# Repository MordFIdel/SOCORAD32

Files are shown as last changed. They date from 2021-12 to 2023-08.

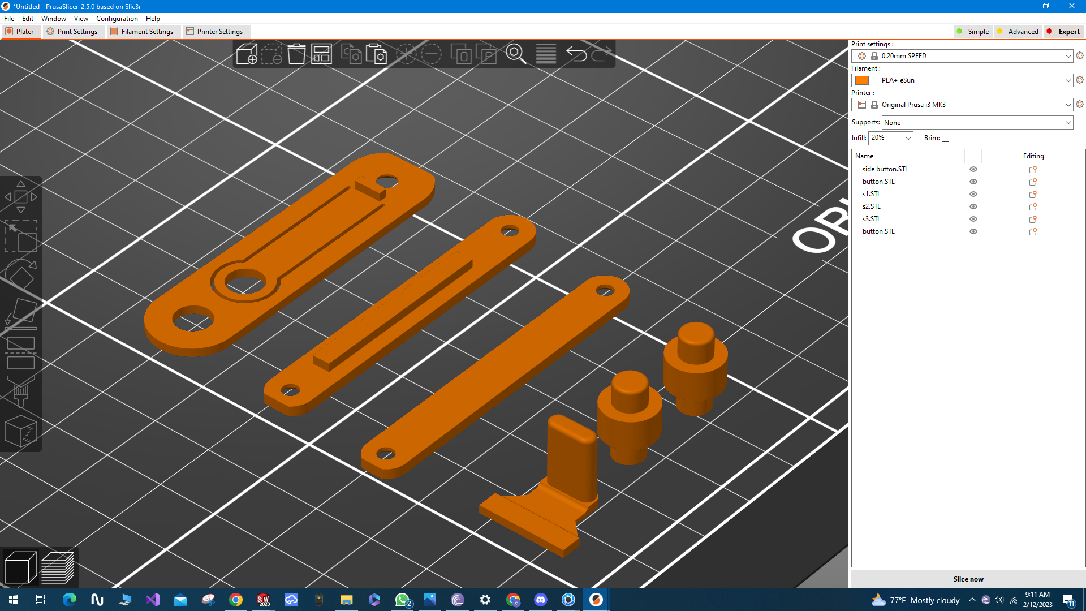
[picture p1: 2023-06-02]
3D_Files/Inner arrangement components.png

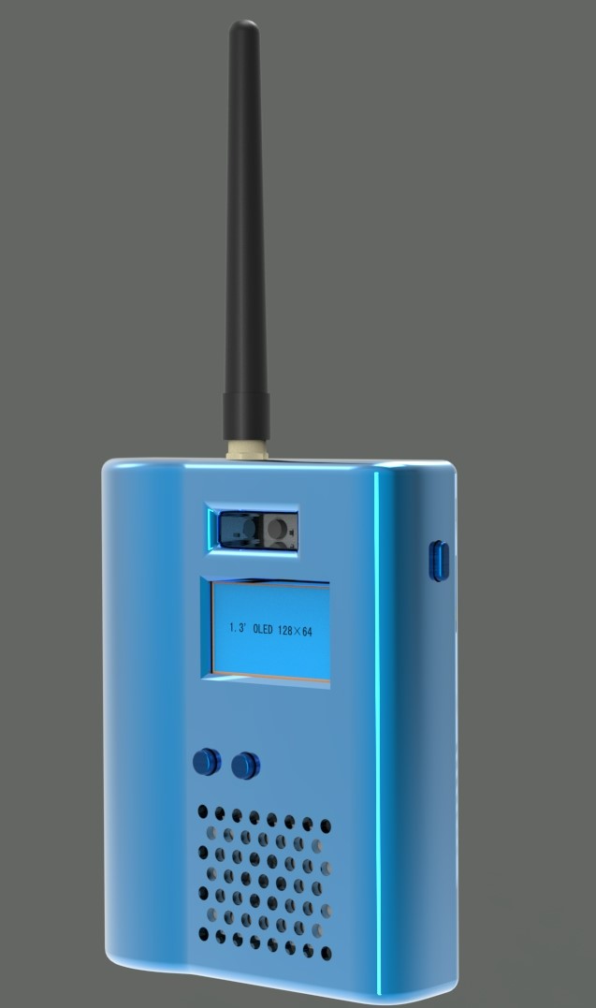
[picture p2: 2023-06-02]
3D_Files/3D.jpg

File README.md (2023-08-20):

# SOCORAD32 - ESP32 SOftware COntrolled RADio

<br/> (3D enclosure design already released)
<br/>
<br />Add a speaker and a battery, then you'll have a fully functional walkie talkie Radio. It shares the same properties as the commercial one. Can be used both for voice and data communication. Because it can communicate data, we can explore the amateur radio frequency for IoT.
<br/>Beyond communication, it is fully open source and hackable!
<br />The central module contains the special purpose RDA1846 IC. This same IC is used in commercial walkie talkies such as in Baofeng and Hytera. <br/>

<br/>Other of its peripherals is an onboard ESP32 for parameter settings (via Bluetooth or WiFi), control and storage. 
<br/>The ESP32 talks to the central module using simple AT commands. The specifications are listed below.

# Specifications
Frequency Range: 400-470mhz covers most countries allocated walkie talkie frequencies, especially the license free ones.
<br/> Frequency Step: 5K/6.25K/12.5K/25K
<br/> RF Output Power: 2W/1W/0.5W
<br/> Voice features, Tone Squelches, SMS cabapility:
<br/> Voice encryption (scrambling): 8 types
<br/> SMS Receive/Transformer, baudrate: 1200
<br/> CTCSS (38 groups) + CDCSS (83 groups)
<br/> Automatic elimination tail
<br/> Volume adjustable (1-8)
<br/> Squelch level adjustable (0-9)
<br/> MIC sensitivity level adjustable (1-8)
<br/> Sleep Mode (0.1μA)
<br/><br/>To talk to the module, a generic Bluetooth serial communication APP is used on the phone to connect to the ESP32 module which in turn communicates with the RF module via UART. Due to the SOCORAD32 rich features, it can be used for the following applications.

# Applications
Walkie Talkie
<br/>Intercom
<br/>Pager
<br/>IoT (data transmission module)
<br/><br/>The AT commands are in the repository. It includes commands for volume control, power output, RX/TX frequencies, voice activated exhange, squelching, etc.
<br/>The device contains a dedicated PTT button and extra buttons for user configurations.

<br/>SOCORAD32 high rez

## First run / Flashing
See [Final Firmware](Final_Firmware.md) for instructions

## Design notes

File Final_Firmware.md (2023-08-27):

Remember the changes we promised. It's here. The old software has too much bugs and so we decided to make this new one, using Bluetooth Low Energy. once you receive your unit. Just follow the simple steps below.

## ESP-IDF

This software is written in vs code using the [v4.4.4 ESP-IDF](https://github.com/espressif/idf-installer/releases/download/offline-4.4.4/esp-idf-tools-setup-offline-4.4.4.exe)

## Channels

Once you load this software, you can change the channel and volume with the provided buttons on the PCB. 
The channels are what is stored in the code. You are free to change the channel anyway you want, 
just edit the channel storage section in the code. Up to 50 channels or more can be edited to your
preference. 
To change the channel, Press and hold the button. To change volume, press once to change volume.
Connecting to your bluetooth phone, you can use the bluetooth serial software to also change channel by sendng AT+DMOCHN=8 (for channel 8)
AT+DMOCHN=10 (for channel 10).

### Edit Default Channels

To edit channel list, in the zip file, navigate to main, then ui.c You'll find this section at the top part of the code. 
This is same  for editing the ctcss. See screenshots below.

Channel list

ctcss list

## Bluetooth connection

This software allows simple and less complex use of the SOCORAD32 directly without bluetooth connection. 
Other functions provided by the walkie talkie module are accessible via bluetooth connections to a mobile device.
The connection process is simple. Using the 'Serial Bluetooth Terminal' android app as example (get from PlayStore), 

1. Firstly, connect the SCRD32 to your phone following your phone standard connection process. Passkey is 123456
2. Press the Menu button
3. Select Devices
4. Select Bluetooth LE
5. Press and hold the listed BLE device and choose edit.
6. Choose custom and enter the details as shown in the image below.

BLE connect process

7. Save the settings and voila!, your SOCORAD32 is connected. You can now use the AT commands directly. Input your commands through the app and view response from the SOCORAD32.

## Firmware

Link to FIrmware https://github.com/MordFIdel/SOCORAD32/blob/main/SCRD32%20firmware%20official.zip

## Beginners Guide For Windows

You have to load the firmware to the radio when you get it.
- Download the [ESP-IDF](#ESP-IDF) linked and install it.
- Download the [firmware zip](#firmware), "SCRD32 firmware official.zip", and - Extract the files to a folder with no spaces in name. For example you might extract it to "C:/SCRD32"
- Open the ESP-IDF powershell program
- Navigate to the folder you saved the firmware in, and type ```idf.py build``` This will build the firmware.
- Once the build is complete connect the radio and type ```idf.py -p [Port] flash```

- Change [Port] to the COM port of the socorad I. E. ```idf.py -p COM3 flash``` 

The firmware should now be loaded on the radio.

## Linux / Mac

Useful but optionnal dependency to speedup building: ccache

### Install esp-idf
```
mkdir -p ~/esp
cd ~/esp
git clone --recursive --branch v4.4.4 https://github.com/espressif/esp-idf.git
cd ~/esp/esp-idf
./install.sh esp32
```

### Clone repo
```
cd ~/
git clone https://github.com/MordFIdel/SOCORAD32.git
```
### Build & Flash
```
cd ~/SOCORAD32/SCRD32_firmware_official/
. $HOME/esp/esp-idf/export.sh (Run it everytime before you want to use esp-idf)
idf.py build
idf.py flash
```

You can directly use the esp-idf extension in Visual Code. Take care to utilize the correct version of ESP-IDF.

Or you could follow the [guide for installing the tool directly on Linux / Mac](https://docs.espressif.com/projects/esp-idf/en/latest/esp32/get-started/linux-macos-setup.html#)

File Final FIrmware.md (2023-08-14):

Remember the changes we promised. It's here. The old software has too much bugs and so we decided to make this new one, using Bluetooth Low Energy. once you receive your unit. Just follow the simple steps below.

This software is written in vs code using the [v4.4.4 ESP-IDF](https://github.com/espressif/idf-installer/releases/download/offline-4.4.4/esp-idf-tools-setup-offline-4.4.4.exe)

Once you load this software, you can change the channel and volume with the provided buttons on the PCB. 
The channels are what is stored in the code. You are free to change the channel anyway you want, 
just edit the channel storage section in the code. Up to 50 channels or more can be edited to your
preference. 
To change the channel, Press and hold the button. To change volume, press once to change volume.
Connecting to your bluetooth phone, you can use the bluetooth serial software to also change channel by sendng AT+DMOCHN=8 (for channel 8)
AT+DMOCHN=10 (for channel 10).

To edit channel list, in the zip file, navigate to main, then ui.c You'll find this section at the top part of the code. 
This is same  for editing the ctcss. See screenshots below.

Channel list

ctcss list

This software allows simple and less complex use of the SOCORAD32 directly without bluetooth connetion. 
Other functions provided by the walkie talkie module are accesssible via bluetooth connections to a mobile device.
The connection process is simple. Using the 'Serial Bluetooth Terminal' android app as example (get from PlayStore), 

1. Firstly, connect the SCRD32 to your phone following your phone standard connection process. Passkey is 123456
2. Press the Menu button
3. Select Devices
4. Select Bluetooth LE
5. Press and hold the listed BLE device and choose edit.
6. Choose custom and enter the details as shown in the image below.

BLE connect process

7. Save the settings and voila!, your SOCORAD32 is connected. You can now use the AT commands directly. Input your commands through the app and view response from the SOCORAD32.

Link to FIrmware https://github.com/MordFIdel/SOCORAD32/blob/main/SCRD32%20firmware%20official.zip

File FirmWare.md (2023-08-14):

[Firmware and guideline.zip](https://github.com/MordFIdel/SOCORAD32/files/10908223/Firmware.and.guideline.zip)

Here is a sample FW. Please note, the firmware is not developed by us, this is the work of the creator, DragonTV. KM6WZM
Please find him at https://www.instructables.com/member/dragonbtv/
The FirmWare is discussed at https://www.instructables.com/Arduino-Walkie-Talkie/

Thanks!

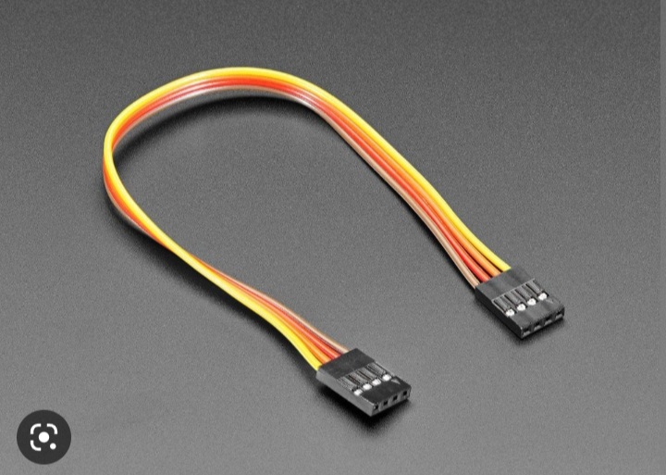
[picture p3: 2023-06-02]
3D_Files/display connector.jpg

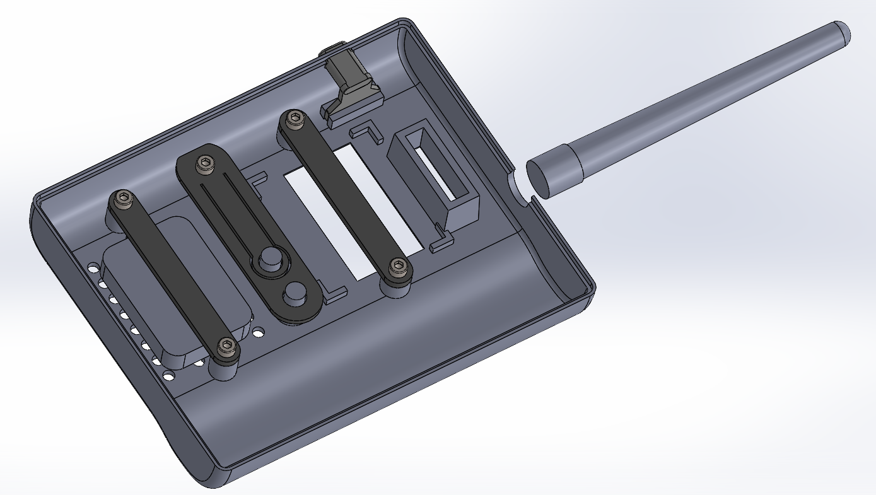
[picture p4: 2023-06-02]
3D_Files/Inner arrangement.png

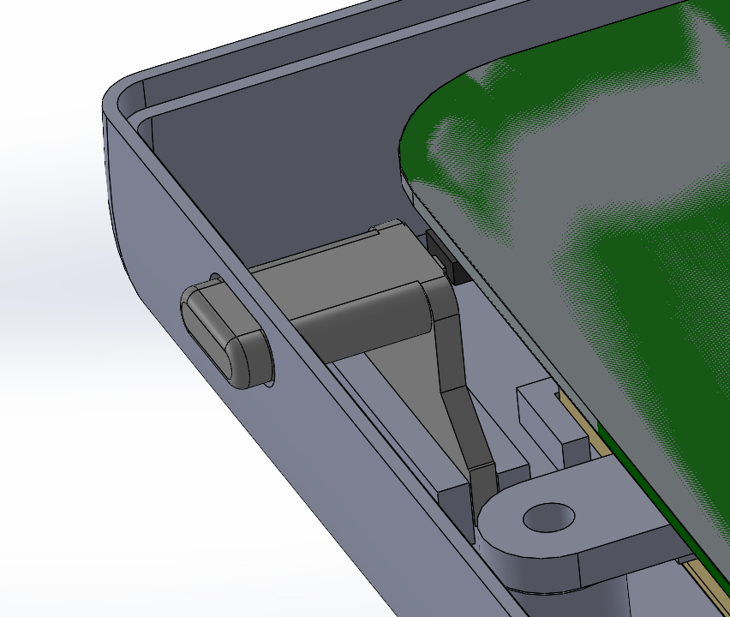
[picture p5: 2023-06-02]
3D_Files/button arrangement.png

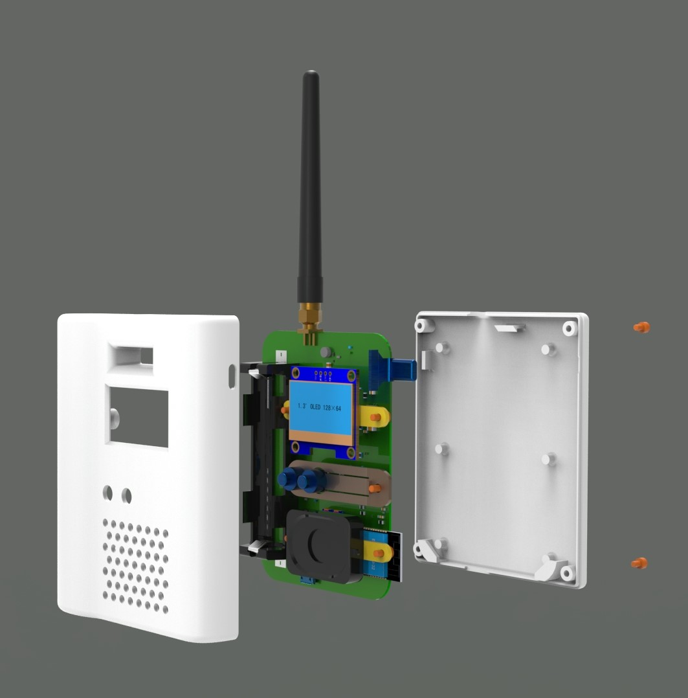
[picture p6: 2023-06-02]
3D_Files/exploded view original.jpg

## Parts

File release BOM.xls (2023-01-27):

Item # | *Designator | *Qty | *Mfg Part # | Description / Value | *Package/Footprint | Your Instructions / Notes | *Actual Purchase Mfg Part #
1 | C1, C9, C18, C21, C25, C32 | 6 | 10uf | 10µF ±10% 10V Ceramic Capacitor X5R 0603 _1608 Metric_ | 0603 |  | CC0603KRX5R6BB106
2 | C2, C10, C23 | 3 | GRM21BR71A225KA01L | SMT 0805 ceramic cap X7R 10V 2.2uF | 0805
3 | C3, C5, C6, C8, C11, C15, C17, C20, C24, C26, C28, C30, C35 | 13 | 100nf | 0.1ÂµF Â±10% 16V Ceramic Capacitor X7R 0402 _1005 Metric_ | 0402 |  | CC0402KRX7R7BB104
4 | C4, C14 | 2 | 220uf_6v3 | GRM31CR60J227ME11L | 1206 |  | GRM31CR60J227ME11L
5 | C7, C13, C16, C22, C27, C36 | 6 | CL05B104K05NNNC | Multilayer Ceramic Capacitors MLCC - SMD/SMT 100nF+/-10% 16V X7R 0402 | 0402
6 | C19 | 1 | GCM1885C2A2R0BA16D | SMD Capacitor C0G(EIA) with Capacitance: 2.0pF Tol. 0.1pF. Rated Voltage: 100Vdc | 0603
7 | C29 | 1 | GCM1885C2A6R0BA16D | SMD Capacitor C0G(EIA) with Capacitance: 6.0pF Tol. 0.1pF. Rated Voltage: 100Vdc | 0603
8 | C31 | 1 | GCM1885C2A2R5BA16D | SMD Capacitor C0G(EIA) with Capacitance: 2.5pF Tol. 0.1pF. Rated Voltage: 100Vdc | 0603
9 | C33 | 1 | GCM1885C2A4R0BA16D | SMD Capacitor C0G(EIA) with Capacitance: 4.0pF Tol. 0.1pF. Rated Voltage: 100Vdc | 0603
10 | C34 | 1 | CL10A105KP8NNNC | 1µF ±10% 10V Ceramic Capacitor X5R 0603 _1608 Metric_ | 0603
11 | D1 | 1 | SP0503BAHTG | 8.5V Clamp Ipp Tvs Diode Surface Mount SOT-143-4 | SOT-143-4
12 | D3, D5 | 2 | LTST-C191KRKT | Red 631nm LED Indication - Discrete 2V 0603 _1608 Metric_ | 603
13 | D4, D6 | 2 | 19217BHCZL1M2RY3T | blue 0603 Light Emitting Diodes (LED) ROHS | 0603
14 | IC1 | 1 | LM4871 | Audio Amplifiers 3-W, mono, analog input Class-AB audio amplifier 8-SOIC -40 to 85 | 8-SOIC |  | LM4871M/NOPB
15 | J1 | 1 | ZX62-B-5PA(33) | USB - micro B USB 2.0 Receptacle Connector 5 Position Surface Mount, Right Angle
16 | J2 | 1 | CONSMA013.062-G | SMA MALE EDGE MOUNT FOR 0.031 THICK BOARD
17 | L3 | 1 | LQP03TN2N0C02D | FIXED IND 2NH 600MA 150 MOHM SMD | 0603
18 | MIC1 | 1 | GMI4015P-2C-42DB | Through Hole,P=1.4mm Electret Condenser Microphone Source: Datasheet | GMI4015P2C42db
19 | Q3, Q4, Q5, Q6 | 4 | SS8050-G | Bipolar Transistors - BJT NPN TRANSISTOR 1.5A 40V | SOT-23-3 |  | MMBT2222LT1G
20 | R1, R4, R8, R25, R26, R27, R31, R32 | 8 | CRGCQ0805F47K | Fixed Resistor CRGCQ 0805 47K 1% | 0805
21 | R2 | 1 | CRGCQ0805F3K3 | Fixed Resistor CRGCQ 0805 3K3 1% | 0805
22 | R3, R10, R14, R23, R24 | 5 | RC0805FR-0710KL | RES SMD 10K OHM 1% 1/8W 0805 | 0805
23 | R5 | 1 | 1210W2F330LT5E | Thick Film Resistors - SMD 1210 1/2W 1% 0.33R T/R-5000 | 1210
24 | R6, R9, R11, R15, R18, R20, R21, R22, R28, R34 | 10 | 0603WAF1201T5E | Thick Film Resistors - SMD 0603 1/10W 1% 1.2K T/R-5000 | 0603
25 | R7, R12, R13, R17, R19 | 5 | 0402WGF4700TCE | Thick Film Resistors - SMD 0402 1/16W 1% 470R T/R-10000 | 0402
26 | R16, R29, R30, R33 | 4 | AC0402FR-072KL | AC Series 0402 0.063 W 2 kOhm ±1% ±100 ppm/°C SMT Thick Film Chip Resistor | 0402
27 | S1 | 1 | SKSCLAE010 | Black Button Tactile Switch, SPST-NO 50 mA 0.65mm Surface Mount Source: Datasheet
28 | SW1, SW3 | 2 | SKRPABE010 | Switch Tactile N.O. SPST Button J-Bend 0.05A 16VDC 1.57N SMD Automotive T/R
29 | SW4, SW5 | 2 | PTS645SM43SMTR92LFS | C & K COMPONENTS - PTS645SM43SMTR92LFS - SWITCH, SPST, 0.05A, 12VDC, SMD, 4.3MM Source: Datasheet
30 | U1 | 1 | NCP167BMX330TBG | Linear Voltage Regulator IC 1 Output 700mA 4-XDFN _1x1_ | 4-XDFN
31 | U3 | 1 | SR_FRS_2WUS | walkie talkie module
32 | U4 | 1 | TP4056 | Complete single cell Li-Ion battery with a constant current / constant voltage linear charger | SOP-8
33 | U5 | 1 | ESP32-WROOM-32 | SMD MODULE, ESP32-WROOM-32, ESP32-D0WDQ6 |  |  | ESP32-WROOM-32E-N4
34 | U6 | 1 | CH340C | USB to serial chip CH340 | SO-016

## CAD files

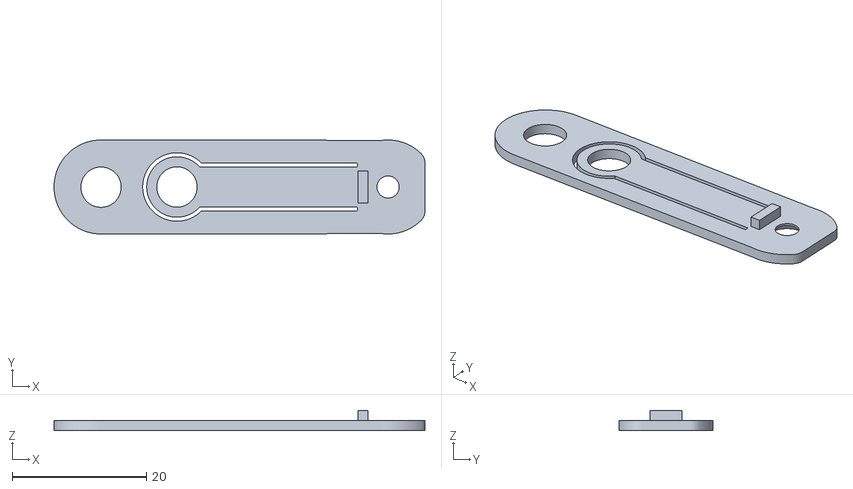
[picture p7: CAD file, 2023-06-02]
3D_Files/s1.STL
55.2 x 14.0 x 3.00

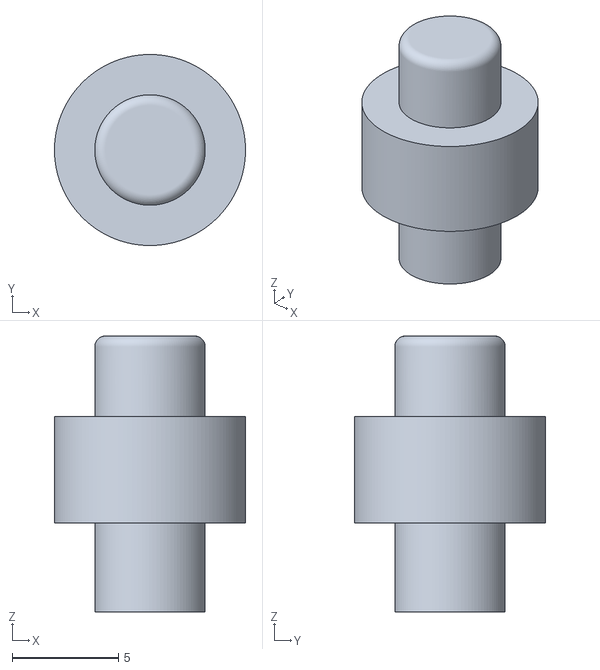
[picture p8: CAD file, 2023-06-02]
3D_Files/button.STL
9.00 x 9.00 x 13.0

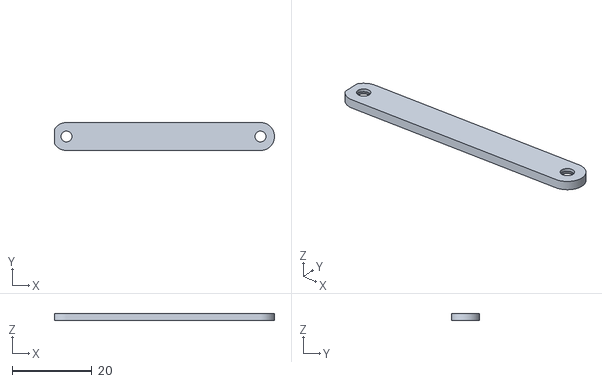
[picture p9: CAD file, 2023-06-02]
3D_Files/s3.STL
55.0 x 7.00 x 1.80

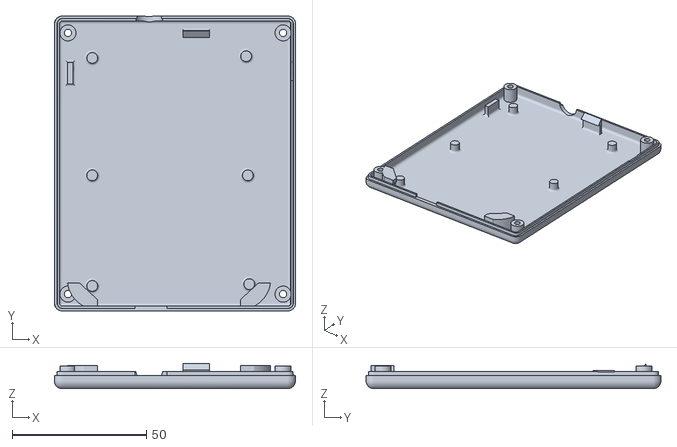
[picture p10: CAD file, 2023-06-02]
3D_Files/V01 - base-1.STL
90.0 x 110.0 x 9.50

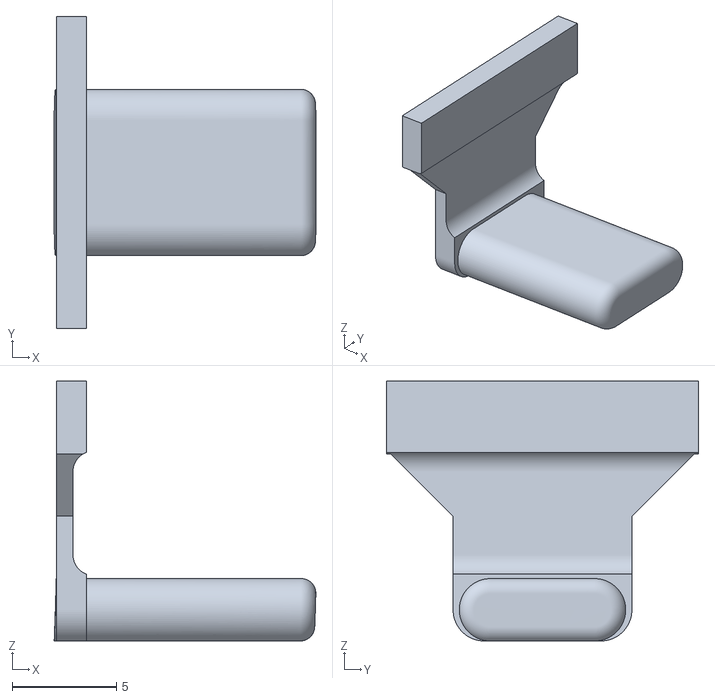
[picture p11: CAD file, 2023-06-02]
3D_Files/side button.STL
12.6 x 15.0 x 12.5

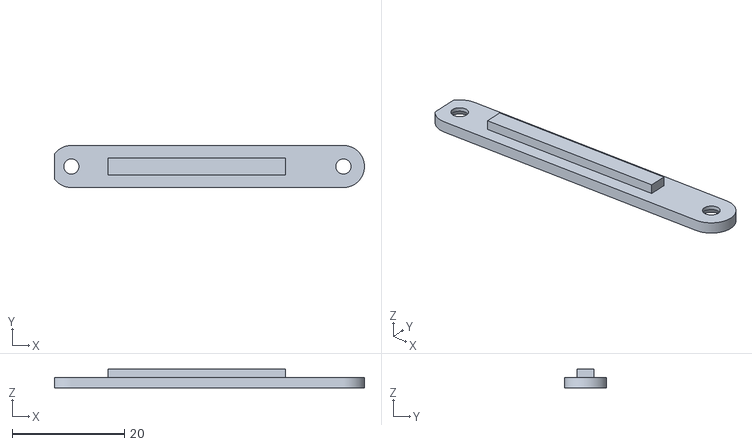
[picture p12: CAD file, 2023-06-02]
3D_Files/s2.STL
55.3 x 7.50 x 3.32

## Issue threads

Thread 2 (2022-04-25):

Can it transmit data from the ESP32?

DurandA, 2022-04-25:
Can the SOCORAD32 transmit data from the ESP32 or is the ESP32 only for the control of the transmission? Can the ESP32 be used to generate DTMF tones?

MordFIdel, 2022-04-26:
Yes it can transmit data from the ESP32. About DTMF, we've are yet to try DTMF, we are not sure.

DurandA, 2022-04-26:
I think from the pictures you are using a SA818 module which doesn't have any digital audio input. Do you feed the MIC input from the ESP DAC? Do you use a discrete chip like I2S->analog?

Also, when do you plan to start the Crowd Supply campaign? Your product sounds awesome.

MordFIdel, 2022-04-27:
I know SA818. The module I am using is slightly different. It houses it's own audio subsystem. The audio is not processed via ESP32. Although it is also a great idea to do that via DAC. The ESP32 only for controls and data transmission.

joyel24, 2023-01-20:
In my opinion, DAC from esp32 to the rf module is a feature that it must include.
It can be very useful to implement new data transmission protocols.
ADC would also be nice as it becomes possible to decode things directly from the ESP32.
A relatively simple circuit implementation but with a huge possible benefits in the end !

MordFIdel, 2023-01-20:
Yes, these are good ideas. For example, the DAC will enable direct audio transmission from a mobile phone for example. Mobile phone audio→Bluetooth→ESP32→DAC→RF module

I will look into this.

MordFIdel, 2023-01-20:
Yeah

lyusupov, 2023-03-07:
1. https://github.com/nakhonthai/ESP32IGate
2. https://github.com/erstec/APRS-ESP

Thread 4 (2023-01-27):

Open hardware?

dietervansteenwegen, 2023-01-27:
Since the crowd funding campaign states "All documentation and project files are available in our GitHub repository.", I expected more than a single arduino file and a pdf. Where can I find the promised board files/schematics/bom?

I understand the focus at the moment is to get the campaign to succeed so I don't expect perfect documentation, but still I'd like to be able to take a look and judge the design before participating instead of going solely by some descriptions.

Thanks.

MordFIdel, 2023-01-27:
Yes things are as promised. We just wanted to make sure we supply the best docs because our prototype has gone through several iterations. Files are almost ready. Will all be uploaded before the start of the new week.

joyel24, 2023-01-27:
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

I think it's coming, I have also been surprised that this repository is almost empty. Only a simple Arduino ide code that handle AT commands from Bluetooth.
Actually no library, no schematics, no ui for the screen, no interaction with esp32 except the at Bluetooth commands, no documentation...
I hope we will see more information on this repository before the end of crowdfunding. 🙂

MordFIdel, 2023-01-27:
Sure you will, before start of new week. Thereafter we will keep adding more and more.

dietervansteenwegen, 2023-01-27:
> Sure you will, before start of new week. Thereafter we will keep adding more and more.

Glad to hear that. I understand documentation might not feel like a priority but no documentation at all makes it very difficult to judge what you are going to sell.

Looking forward to the design files (and thanks for the quick response)!

joyel24, 2023-05-26:
Issue can be closed I guess

Closed 2023-06-25.

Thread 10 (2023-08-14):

A suggestion of software add-ons

Steph-owb, 2023-08-14:
Dear Mordecai,

As SOCORAD32 is well suited for many applications i would suggest to include in the software the following:

- A receive function with data decoder for EPIRBs in 406 Mhz this would be extremey uefull in case false alarm or real life emergency messages
- A receive function with data decoder for Boats tracking  AIS VHF system messages
- A receive function with data decoder for Radiosonde Decoding such as the Lora32 solution created by Mirko Dalmonte (IZ4PNN)

With such add-ons the SOCORAD32 would bring very interesting features which are not usually fould together in a radio device...

Thanks a lot for your consideration
Stephan

MordFIdel, 2023-08-14:
Awesome, I'll look into all these functions.

Thank You!

On Mon, Aug 14, 2023 at 2:24 PM Stephan F5OWB ***@***.***>
wrote:

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

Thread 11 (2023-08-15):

step-by-step instructions for firmware build/load

KillerTurtleSoftware, 2023-08-15:
Can there be a good step-by-step instruction for the building and loading of the firmware.
was hoping to get the units and be able to use them right out of the box, but screen shows nothing, and no buttons work.  I understand we have to load the initial firmware now.  I do have esp idf tools and vs code installed.

MordFIdel, 2023-08-15:
Hi, that is not supposed to be. I'll check that on my end here. Does the Rx LED comes when receiving.?

KillerTurtleSoftware, 2023-08-15:
The Rx LED does come on.  The TX LED only goes off , when the walkie-talkie transmits.

MordFIdel, 2023-08-16:
> same here. Also could only upload firmware while pressing PTT. not sure if all that is intentional.

I think the TX light always on is an issue in the code. Only able to upload a code when you press PTT is not normal. I think that was a coincidence. apologies

KillerTurtleSoftware, 2023-08-16:
> same here. Also could only upload firmware while pressing PTT. not sure if all that is intentional.

I wonder if this was related to my not being able to upload on one device issue. Does the PC not detect the SOCRAD is connected until you press PTT? I let it sit overnight and then it started working right.

I am going to try some changes to the firmware tonight and see what works.

MordFIdel, 2023-08-16:
Please also make sure you have the battery in when plugged to pc. The USB
power from pc alone is not enough

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

KillerTurtleSoftware, 2023-08-16:
Ok found the issue, the PTT line is normally HIGH (1) not LOW(0), due to RF module grounding pin to start PTT
In main.c on line 344  it is
        gpio_set_level(LED_TX_PIN, !gpio_get_level(TX_STATE_PIN));
this should be
        gpio_set_level(LED_TX_PIN, gpio_get_level(TX_STATE_PIN));
I have tested it and it fixes the TX LED, so now it comes on when you TX.

lsascha, 2023-08-17:
> Does the PC not detect the SOCRAD is connected until you press PTT? I let it sit overnight and then it started working right.

My main PC did not want to detect it at all. But that could be some yet to me unknown software problem on my PC side.
On my notebook it detected them, but they always connected, disconnected more or less constantly until sometimes it stopped. But on trying to flash the firmware, it disconnected again in the middle of it which resulted in an error about access right issues to the port or something.

KillerTurtleSoftware, 2023-08-17:
> > Does the PC not detect the SOCRAD is connected until you press PTT? I let it sit overnight and then it started working right.
>
> My main PC did not want to detect it at all. But that could be some yet to me unknown software problem on my PC side. On my notebook it detected them, but they always connected, disconnected more or less constantly until sometimes it stopped. But on trying to flash the firmware, it disconnected again in the middle of it which resulted in an error about access right issues to the port or something.

2 things to try, 1 another usb cable, 2, try a usb 2.0 port not a usb 3 port.

MordFIdel, 2023-08-17:
The programming issues are usually due to power(low battery) or communication(wrong USB cable) issues.

lsascha, 2023-08-17:
since both my PC's don't have a USB 2.0 port anymore i am stuck with USB 3 or USB-C. And my selection of Micro USB cables are a bit limited as well. And i don't have a fitting battery.. 🙈

But it could also explain why they also reboot every time i press the PTT button.

I will see that i source some Micro USB cable and/or a battery to try them out correctly. Not sure what to do about USB 2.0 ports though...

KillerTurtleSoftware, 2023-08-17:
I only have USB3.0 ports on my laptop as well. I've seen where some things just don't like the speed of a USB3.0 port.  If it's an issue normally you can get a cheap USB2 hub and that works.
Yep definitely need a battery, just wish there was a on/off switch.

lsascha, 2023-08-23:
Received Batteries today. No issues of flashing or pressing PTT anymore. So a Battery is mandatory for it to function. Didn't know that. So all is fine.

joyel24, 2023-08-24:
I fixed this in this pull request:
https://github.com/MordFIdel/SOCORAD32/pull/22

joyel24, 2023-08-26:
@MordFIdel You can merge the PR and close this issue after ;)

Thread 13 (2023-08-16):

Changing settings VIA BLE doesn't show on screen

KillerTurtleSoftware, 2023-08-16:
I've noticed if I change the VOX or Volume via BLE it changes, but the screen doesn't reflect the new value.

Also, Mic gain level seems to be adjusted when I sent the AT_DOMVOX=X.

I have a communications system analyzer at work that I will test on.

joyel24, 2023-08-27:
In my case, I won't fix this because I'm working on a completely other way to control the vox lvl.

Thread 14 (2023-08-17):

won't power on

03escape, 2023-08-17:
Can't find a power button,  screen won't come on.

KillerTurtleSoftware, 2023-08-17:
You have to load the firmware to the radio when you get it.
Download the ESP-IDF linked in the "final Firmware.md" and install it.
Download the firmware zip, "SCRD32 firmware official.zip", and extract the files to a folder with no spaces in name. I downloaded it to "C:/SCRD32"
Open the ESP-IDF powers he'll program and navigate to the folder you saved the firm in, and type "idf.py build"
This will build the firmware then once complete, connect the radio and type "idf.py -p [Port] flash"

Change [Port] to the Comm port of the socorad I. E. "idf.py -p com3 flash

MordFIdel, 2023-08-17:
Perfect. Thanks

KillerTurtleSoftware, 2023-08-18:
I created a detailed step-by-step guide on the site I created, here http://socorad32.killerturtle.tech/showthread.php?tid=1

joyel24, 2023-08-25:
@03escape or @MordFIdel:
Can you close this issue please.

Closed 2023-10-06.

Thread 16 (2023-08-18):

No COM port

imagesafari, 2023-08-18:
Drivers and ESP IDF installed, etc - no COM port shows up. Win 11.

KillerTurtleSoftware, 2023-08-18:
try different cable, some are just for charging. Also try charging the battery for a little while before trying to connect.  You must have the battery installed as well. Laos try another USB port, or another PC.

I had the same issue until I let it charge over night, and plugged it into a different computer, now it works every time.

imagesafari, 2023-08-18:
Yeah, I did that - still nothing. Tried it on two different PCs.

On Fri, Aug 18, 2023 at 2:31 PM Mordecai Raji ***@***.***>
wrote:

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

imagesafari, 2023-08-18:
Ok, I'll give that a shot.

On Fri, Aug 18, 2023 at 3:00 PM Killer Turtle ***@***.***>
wrote:

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

joyel24, 2023-08-25:
This video is an entire guide for windows to build & flash the firmware. It also includes the link for the ch340 driver in the description in case of no serial device is detected.

https://youtu.be/jlW-oVTjPQg?feature=shared

MordFIdel, 2025-07-20:
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

Some cables can only do charging. Make sure the cable description says chasing plus data

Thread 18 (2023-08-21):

Can you make a real wiki how to build and flash on linux or macos ?

joyel24, 2023-08-21:
Can you write instructions to build and flash the firmware on linux or macos ?
Or at least can you build it and publish it in the release section and make a simple how to flash in every os...
I'm not sure everyone wants to install all dependencies and build their own firmware.

I just installed "ESP-IDF v4.4.4-dirty" confirmed with `idf.py --version` and it fails  when trying to build on macos 12.6.

```
Processing 1 dependencies:
[1/1] idf (4.4.4)
-- DEBUG: Use esp-modbus component folder: /Users/joel/esp/esp-idf/components/freemodbus.
-- Project sdkconfig file /Users/joel/Downloads/SCRD32 firmware official/sdkconfig
Traceback (most recent call last):
  File "/Users/joel/esp/esp-idf/tools/kconfig_new/confgen.py", line 644, in <module>
    main()
  File "/Users/joel/esp/esp-idf/tools/kconfig_new/confgen.py", line 264, in main
    config = kconfiglib.Kconfig(args.kconfig)
  File "/Users/joel/.espressif/python_env/idf5.0_py3.10_env/lib/python3.10/site-packages/kconfiglib.py", line 947, in __init__
    self._init(filename, warn, warn_to_stderr, encoding)
  File "/Users/joel/.espressif/python_env/idf5.0_py3.10_env/lib/python3.10/site-packages/kconfiglib.py", line 1085, in _init
    self._parse_block(None, self.top_node, self.top_node).next = None
  File "/Users/joel/.espressif/python_env/idf5.0_py3.10_env/lib/python3.10/site-packages/kconfiglib.py", line 2982, in _parse_block
    prev = self._parse_block(None, parent, prev)
  File "/Users/joel/.espressif/python_env/idf5.0_py3.10_env/lib/python3.10/site-packages/kconfiglib.py", line 2970, in _parse_block
    raise KconfigError(
kconfiglib.KconfigError: kconfigs_projbuild.in:6: '/Users/joel/Downloads/SCRD32' not found (in 'source "/Users/joel/Downloads/SCRD32"'). Check that environment variables are set correctly (e.g. $srctree, which is unset or blank). Also note that unset environment variables expand to the empty string.
CMake Error at /Users/joel/esp/esp-idf/tools/cmake/kconfig.cmake:266 (message):
  Failed to run confgen.py
  (/Users/joel/.espressif/python_env/idf5.0_py3.10_env/bin/python;/Users/joel/esp/esp-idf/tools/kconfig_new/confgen.py;--kconfig;/Users/joel/esp/esp-idf/Kconfig;--sdkconfig-rename;/Users/joel/esp/esp-idf/sdkconfig.rename;--config;/Users/joel/Downloads/SCRD32
  firmware official/sdkconfig;--defaults;/Users/joel/Downloads/SCRD32
  firmware
  official/sdkconfig.defaults;--env-file;/Users/joel/Downloads/SCRD32
  firmware official/build/config.env).  Error 1
Call Stack (most recent call first):
  /Users/joel/esp/esp-idf/tools/cmake/build.cmake:523 (__kconfig_generate_config)
  /Users/joel/esp/esp-idf/tools/cmake/project.cmake:384 (idf_build_process)
  CMakeLists.txt:8 (project)

-- Configuring incomplete, errors occurred!
FAILED: build.ninja
```

KillerTurtleSoftware, 2023-08-22:
Try adding --no-ccache to the build line *not the double cc
I. E. idf.py --no-ccache build

KillerTurtleSoftware, 2023-08-23:
OK. I'll do a build and see what files are needed to be able to run the flash without first building tonight. I'll upload them to the site if I can get it to work.

KillerTurtleSoftware, 2023-08-23:
After reading the ESP-IDY getting started guide, https://docs.espressif.com/projects/esp-idf/en/stable/esp32/get-started/linux-macos-setup.html
it looks like it checks the build file and rebuilds it, if needed, when running the flash command. So it looks like you will probably have to install the required dependencies.

From what I've read further, you may be able to share all the built files, but I have to do some testing to see how well it works.

Also, I build the file each time, as I change the Bluetooth name between the 2 radios, so I know which is which when I connect to my phone.

joyel24, 2023-08-24:
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

The extracted archive is here:
/Users/joel/Downloads/SCRD32

When I list this directory, there is no preblem:
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

joyel24, 2023-08-25:
I tried reinstalling esp-idf and updated all git dependancies and it appears to work now.
In my fork I updated the building guide Final_Firmware.md: https://github.com/joyel24/SOCORAD32/blob/main/Final_Firmware.md

Closed 2023-08-25.

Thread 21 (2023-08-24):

How to remove tone code CTCSS ?

joyel24, 2023-08-24:
I am trying to disable the tone code CTCSS and pushed 0 to RxCT & TxCT but the tone is still on.

In my ui.c below, you can find that all first 16 channels has been modified.
I disabled the VOX with 0 and wanted to do the same for tone but it's not working as I expected.
https://github.com/joyel24/SOCORAD32/blob/PMR446/SCRD32_firmware_official/main/ui.c

The doc about the firmware talks about "editing the ctcss" but not about disabling it completely.
[The documentation ](https://github.com/MordFIdel/SOCORAD32/blob/main/Final_Firmware.md)

Can i have some help please ?

This video shows the issue:
https://youtu.be/DQbvcjrrRdY?feature=shared

KillerTurtleSoftware, 2023-08-24:
Instead of
`{446.00625,	446.00625,	0,	0,	0,	WIDE_BAND,	HIGH_LEVEL}`
try
`{446.00625,	446.00625,	,	,	0,	WIDE_BAND,	HIGH_LEVEL}`
There is no '0' value in the matrix, so it may be defaulting to the first option. The option may need to be a Null value.  I don't have my radios at work to try.

joyel24, 2023-08-24:
I'll try and tell you...

I saw this function managing ctcss, with interval from 1 to 38 (0 excluded). I thought that when this function returns 0, it disables the tone, but didn't try to understand the code more than that.

static float getToneFreq(uint8_t ctcss_code)
{
	if (ctcss_code > 0 && ctcss_code <= 38)
		return tone_freq[ctcss_code-1];
	else
		return 0;
}

KillerTurtleSoftware, 2023-08-24:
I saw that code too, but it's only used once, Line 303, and that line is commented out.

The Radio module doesn't have any mentions of what code is needed to disable the tones, just how to set them.

joyel24, 2023-08-24:
` ui.c:23:25: error: expected expression before ',' token {446.01875, 446.01875, , , 0, WIDE_BAND, HIGH_LEVEL}, `

That was not a good idea, now it's not compiling at all...
@MordFIdel Can you tell something ? You sell this product and it appears that you have no skills on programming... Strange

joyel24, 2023-08-24:
> I saw that code too, but it's only used once, Line 303, and that line is commented out.

After rechecking, yes this function is still here but not used apparently.

> The Radio module doesn't have any mentions of what code is needed to disable the tones, just how to set them.
Yes, that's why I'm annoyed.

Anyway, thanks for your help @KillerTurtleSoftware.

KillerTurtleSoftware, 2023-08-25:
Ok,

Just tried it and tested with my HackRF One. You can't leave it empty, but the "0" does turn it off'.

KillerTurtleSoftware, 2023-08-25:
> `ui.c:23:25: error: expected expression before ',' token {446.01875, 446.01875, , , 0, WIDE_BAND, HIGH_LEVEL},`
>
> That was not a good idea, now it's not compiling at all... @MordFIdel Can you tell something ? You sell this product and it appears that you have no skills on programming... Strange

This is why I created the site/forum. To have a place to work together and build/test at.

joyel24, 2023-08-25:
> Ok,
>
> Just tried it and tested with my HackRF One. You can't leave it empty, but the "0" does turn it off'.

I don't have the same result, check this video:
https://youtu.be/DQbvcjrrRdY?feature=shared

joyel24, 2023-08-25:
Nut sure but I think I found why it's not working.

After reading schematics I found that PIN14 (SQUELCH) of radio module is connected to PIN5 of our ESP32 MCU but there is didn't find any mention of this pin on the firmware source code.
https://github.com/MordFIdel/SOCORAD32/blob/main/SOCORAD32.PDF

Maybe the squelch level is so high and never toggle RX as it's not in code, the only way to trigger the squelch is to use a Tone code for the moment I suppose... @MordFIdel ?

joyel24, 2023-08-25:
Well I found a solution, it will be in pull request soon

joyel24, 2023-08-25:
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

In fact, originally if ct is set to 0, it will put it automatically to 1:
This is from uart.c
```
if(gRxCtcss == 0) gRxCtcss = 1;
        else if(gRxCtcss > 38) gRxCtcss = 38;

        if(gTxCtcss == 0) gTxCtcss = 1;
        else if(gTxCtcss > 38) gTxCtcss = 38;
```

KillerTurtleSoftware, 2023-08-25:
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

The ESP Pin 5 is SENSOR_VN (GPIO_39). which is referenced in gpio.c as "#define RX_STATE_PIN (GPIO_NUM_39) "
the Squelch is just a output from the RF module, saying it's receiving a signal.

also, it looks like you have to use the AT+DMOFUN command to set the squelch level, haven't seen it set any where.
I will work on adding this line to the uart.c code.  This is really needed as the mic gain level needs to be adjusted as well. I feel it's way too low by default.

joyel24, 2023-08-25:
> The ESP Pin 5 is SENSOR_VN (GPIO_39). which is referenced in gpio.c as "#define RX_STATE_PIN (GPIO_NUM_39) " the Squelch is just a output from the RF module, saying it's receiving a signal.

i know, after reading schematics and RF module datasheet I understood how pin5 works, this basically to toggle an RX led.

> also, it looks like you have to use the AT+DMOFUN command to set the squelch level, haven't seen it set any where. I will work on adding this line to the uart.c code. This is really needed as the mic gain level needs to be adjusted as well. I feel it's way too low by default.

Yes this is possible to change squelch level via bluetooth AT+.
But I can confirm that without choosing a specific squelch level, after sending 0xFF bytes to the RF module for the RXct & TXct its working well with a random Walkie talkie with no CT/DCS

joyel24, 2023-08-26:
fixed by #29

Closed 2023-08-27.

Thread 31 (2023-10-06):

will not find the com port,

03escape, 2023-10-06:
I have tried to get the com port working. different computer, different cables, installing the ch340 driver, tested to make sure date cable was good.

alebarra, 2023-10-26:
same issue for me, two socorad32 ,and in both cases, the serial port disconnect after few second with error:

- [16574.378624] usb 1-2.4.4.2: ch341-uart converter now attached to ttyUSB0
- [16574.559685] usb 1-2.4.4.2: USB disconnect, device number 17
- [16574.560141] ch341-uart ttyUSB0: ch341-uart converter now disconnected from ttyUSB0
- [16574.560190] ch341 1-2.4.4.2:1.0: device disconnected

i m using ubuntu 22.04 lts and I have no problem flashing other esp32 devices.
**with same pc and cable**, flashing  on d1-r32 esp32 device with ch341 serial converter, firmware flashing is completed successfully
could it be a faulty ch341 ?

MordFIdel, 2023-10-27:
I think you are using the PC USB power supply only. Please ensure battery is installed and charged as well. Disconnection after a while is usually due to abrupt power supply.

alebarra, 2023-10-27:
> I think you are using the PC USB power supply only. Please ensure battery is installed and charged as well. Disconnection after a while is usually due to abrupt power supply behaviour.

True, using a well charged battery (LG cell)  the tty not disconnect anymore.

Thank you, it solved for me

kermitdafrog8, 2023-11-03:
I have issues with my device not showing up.  I've tried different PC's, cables, and batteries.  Nothing seems to work.

MordFIdel, 2023-11-03:
Please try reinstalling the USB driver

kermitdafrog8, 2023-11-03:
I've tried the one that came with the 6.1.61 kernel.  I've tried different ones from different downloads.  None of them work for me.

MordFIdel, 2023-11-04:
Make sure battery is installed. This is probably driver or cable issue. It's either of the two.

alebarra, 2023-11-04:
@kermitdafrog8  try following step:

- assure your 18650 battery is well charged (~4.2V) ;
- put battery in battery holder, the blue "Done" led and red "chrg" must be off;
- insert cable, and check led status, only red "chrg" led must be on, if led and blue flashing, you have battery issue, change battery;
- if only red "chrg" led is on, your circuit is ok;
- check your linux kernel driver, ch340c (ch341.ko driver) must be patched in some kernel version,  one that works is [https://github.com/juliagoda/CH341SER], remember to blacklist kernel module ch341

kermitdafrog8, 2023-11-06:
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

I did everything listed.  Everything is correct but dmesg shows no changes when plugging in the device.  lsusb does not show the device either.

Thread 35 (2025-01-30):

Issue with SOCORAD32: Screen not turning on and Bluetooth not connecting

marta253, 2025-01-30:
I recently purchased three SOCORAD32 units, and all of them are experiencing the same issue. The screen does not turn on, and the device does not appear when trying to connect via Bluetooth on a mobile phone. The only functionality that seems to work is voice transmission, however, without access to the screen or Bluetooth settings, it is not possible to change the transmission frequency or power.

Could you please provide guidance on how to resolve this issue? I've used this device before but never had this problem.

MordFIdel, 2025-01-30:
Hi, sorry to hear about that. Are they programmed?

marta253, 2025-01-30:
No, we haven't programmed them. We are using them as they came out of the box, just like we've done with previous units that worked fine.

________________________________
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

MordFIdel, 2025-01-30:
The devices are not programmed from sale. Please follow the instructions in this repository to program it

joyel24, 2025-01-31:
@marta253 the easiest way to flash:
https://youtu.be/p8CsZYtNyKA

Closed 2025-01-31.

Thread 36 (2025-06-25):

Hardware Specifications

thanhphucse, 2025-06-25:
Thank you for creating a useful open-source project!

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

In the project’s datasheet, the connection between the SR_FRS_2WUS module and the antenna involves two inductors and one capacitor (L1, L2, C12) whose specifications are missing. Are their values important, and if so, what values should they have for optimal performance?

Thankk you very much!

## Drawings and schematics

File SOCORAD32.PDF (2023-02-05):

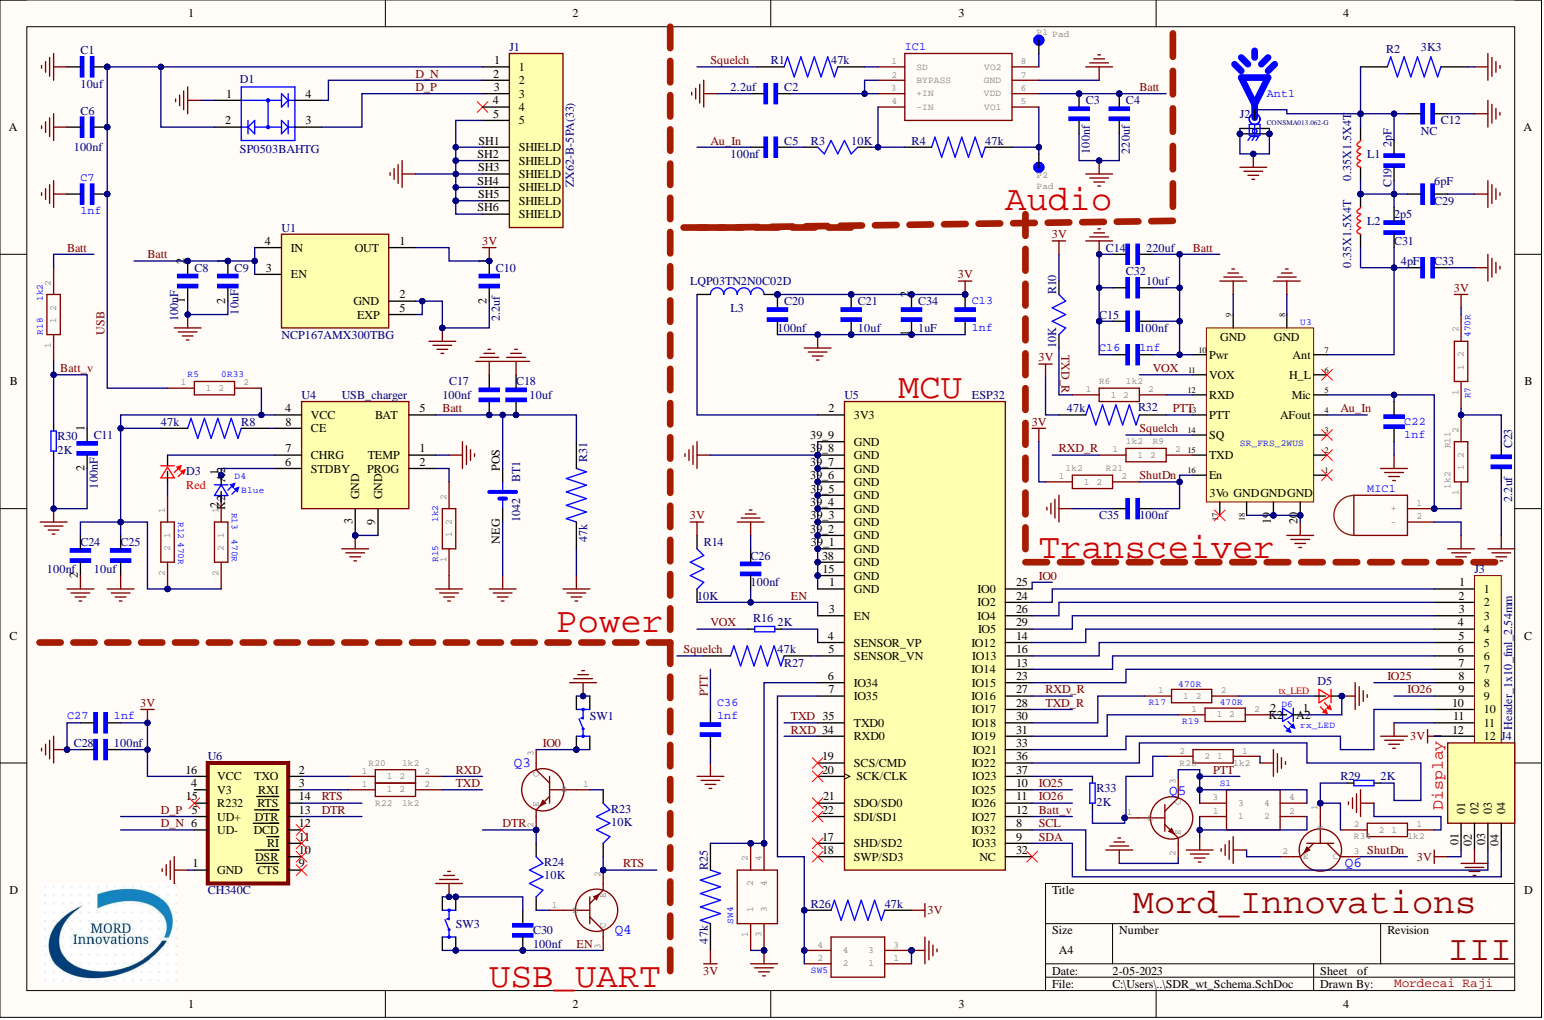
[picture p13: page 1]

SHIELD SH1
SHIELD SH2
SHIELD SH3
SHIELD SH4

SENSOR_VN 5 | | | 6 6
IO34 6 | 7 7
IO35 7 | 470R D5 tx_LED | | 9 9

TXD | TXD0 35 | | TXD_R | | 10 10

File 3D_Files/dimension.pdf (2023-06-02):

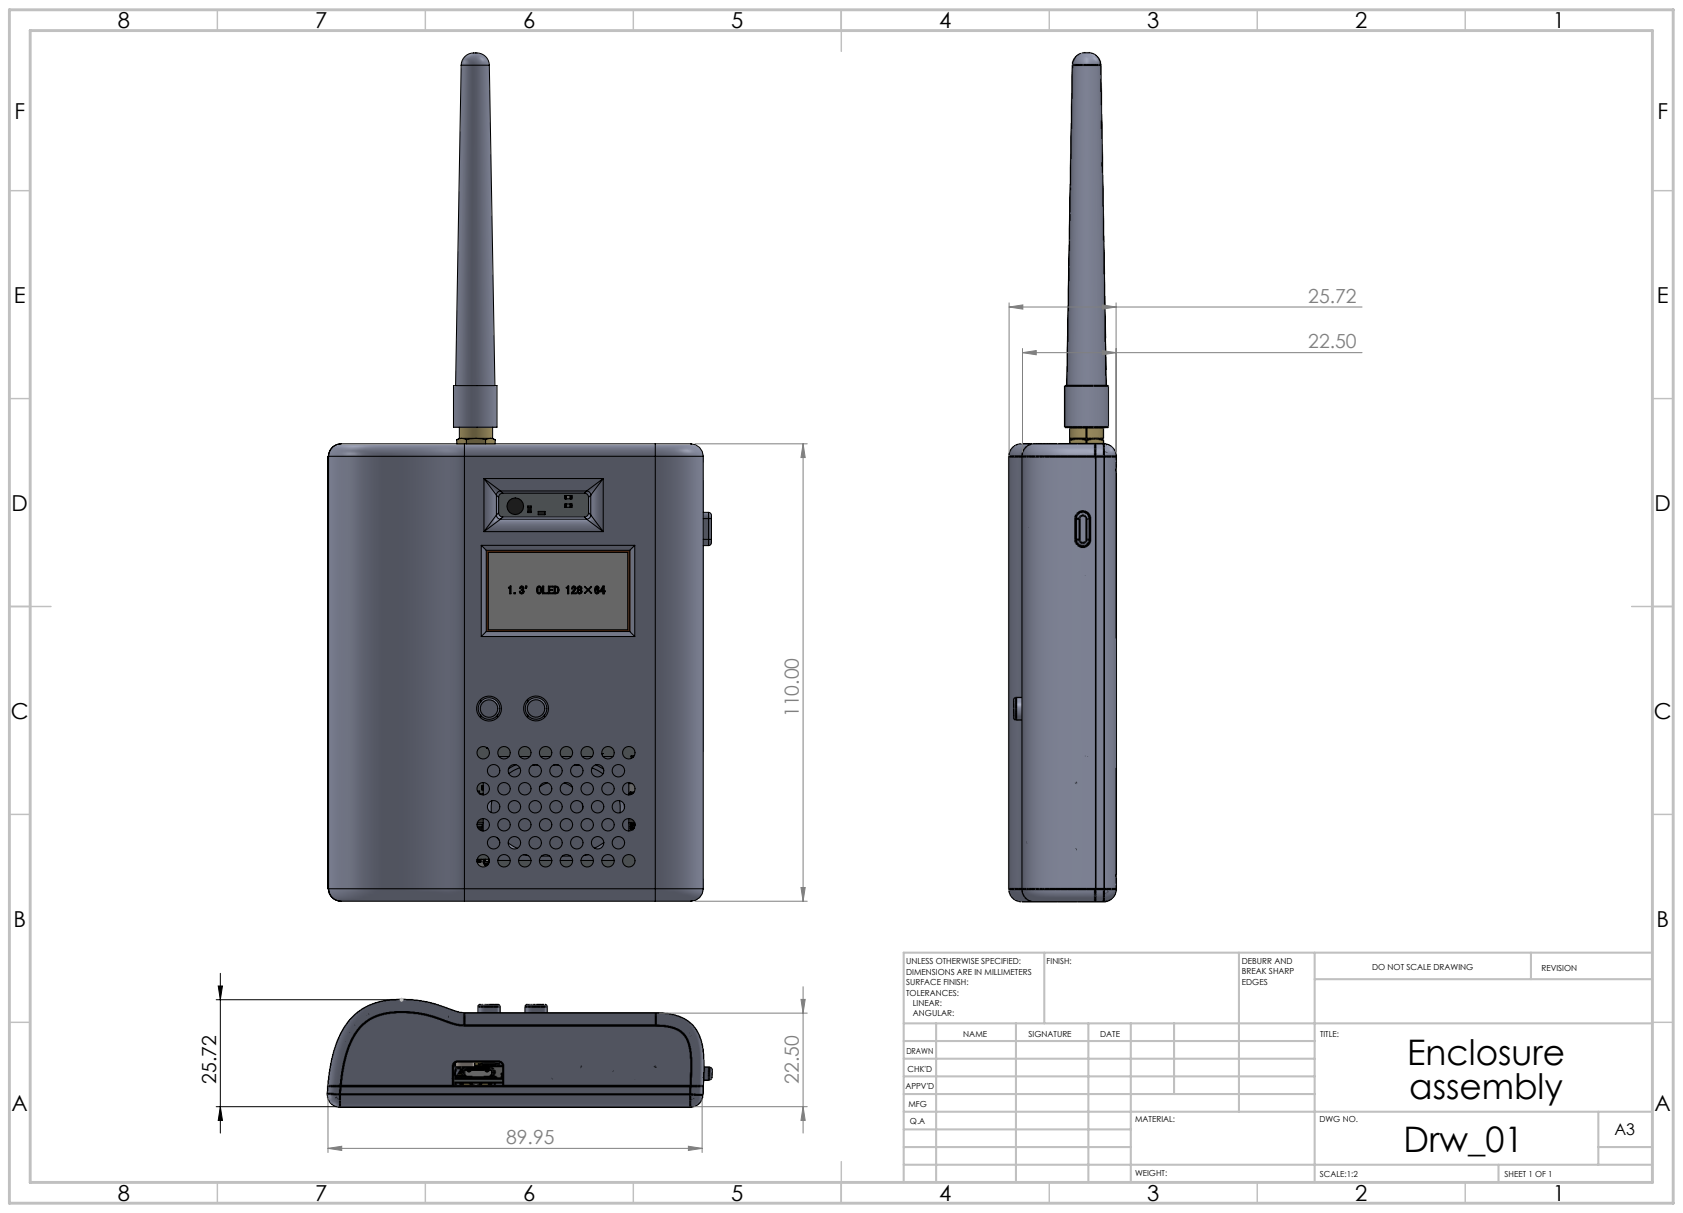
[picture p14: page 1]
FINISH:; DEBURR AND; BREAK SHARP; DO NOT SCALE DRAWING; REVISION; SCALE:1:2; SHEET 1 OF 1

UNLESS OTHERWISE SPECIFIED:
DIMENSIONS ARE IN MILLIMETERS
SURFACE FINISH:
TOLERANCES:
LINEAR:
ANGULAR:

NAME | SIGNATURE | DATE | | | | TITLE: Enclosure assembly

DRAWN
CHK'D
APPV'D
MFG
Q.A | | | | MATERIAL: | DWG NO. Drw_01 | A3

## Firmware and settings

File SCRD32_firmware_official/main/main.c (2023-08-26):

#include "main.h"

#define TAG "MAIN"

SemaphoreHandle_t State_read_mutex = NULL;

void app_main(void)
{
	esp_err_t ret;

	/* Initialize NVS. */
	ret = nvs_flash_init();
	if (ret == ESP_ERR_NVS_NO_FREE_PAGES || ret == ESP_ERR_NVS_NEW_VERSION_FOUND)
	{
		ESP_ERROR_CHECK(nvs_flash_erase());
		ret = nvs_flash_init();
	}
	ESP_ERROR_CHECK(ret);

	State_read_mutex = xSemaphoreCreateMutex();
	xSemaphoreGive(State_read_mutex);

	if (beginEEPROM(4096) == false)
	{
		ESP_LOGE(TAG, "beginEEPROM fail");
	}

	ble_init();

	xTaskCreatePinnedToCore(uiTask, "uiTask", 4096, NULL, 3, NULL, 1);
	createUartTasks();
	xTaskCreatePinnedToCore(gpioTask, "gpioTask", 4096, NULL, 3, NULL, 1);
	
	while(1) {
		vTaskDelay(100 / portTICK_PERIOD_MS);
	}
}

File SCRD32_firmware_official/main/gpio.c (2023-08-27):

#include "main.h"

// #define BUTTON_STATE_NORMAL_OFF
#define BUTTON_STATE_NORMAL_ON

#define LED_TX_PIN  (GPIO_NUM_18)
#define LED_RX_PIN  (GPIO_NUM_19)

#define RX_STATE_PIN (GPIO_NUM_39)
#define TX_STATE_PIN (GPIO_NUM_36)

#define MIN_BTN_PIN  (GPIO_NUM_25)//(GPIO_NUM_34)
#define PLUS_BTN_PIN (GPIO_NUM_35)

#define GPIO_INPUT_PIN_SEL   (  (1ULL<< PLUS_BTN_PIN) | (1ULL<< MIN_BTN_PIN) | (1ULL<< RX_STATE_PIN) | (1ULL<< TX_STATE_PIN)  )
#define GPIO_OUTPUT_PIN_SEL  (  (1ULL << LED_RX_PIN)  | (1ULL<< LED_TX_PIN ) ) 

bool gVolumePlusBtnClicked = false;
bool gVolumeMinusBtnClicked = false;
bool gVoxPlusBtnClicked = false;
bool gVoxMinusBtnClicked = false;
bool gChannelPlusBtnClicked = false;
bool gChannelMinusBtnClicked = false;

extern uint8_t gVolume;
extern uint8_t gVox;
extern uint8_t gChannelNum;

void Reset_pin(void)
{
  gpio_reset_pin(LED_RX_PIN);
  gpio_reset_pin(LED_TX_PIN);
}

void plus_btn_timer_enable()
{
    timer_set_counter_value(TIMER_GROUP_0, TIMER_0, 0);
    timer_start(TIMER_GROUP_0, TIMER_0);
}

void plus_btn_timer_disable()
{
    timer_set_counter_value(TIMER_GROUP_0, TIMER_0, 0);
    timer_pause(TIMER_GROUP_0, TIMER_0);
}

void minus_btn_timer_enable()
{
    timer_set_counter_value(TIMER_GROUP_0, TIMER_1, 0);
    timer_start(TIMER_GROUP_0, TIMER_1);
}

void minus_btn_timer_disable()
{
    timer_set_counter_value(TIMER_GROUP_0, TIMER_1, 0);
    timer_pause(TIMER_GROUP_0, TIMER_1);
}

void Input_pin_config(void)
{
  gpio_config_t io_conf;
  //interrupt of rising edge
  io_conf.intr_type = GPIO_INTR_ANYEDGE;
  //bit mask of the pins, use GPIO4/5 here
  io_conf.pin_bit_mask = GPIO_INPUT_PIN_SEL;
  //set as input mode
  io_conf.mode = GPIO_MODE_INPUT;
  //diable pull-up mode
  io_conf.pull_up_en = 0;
  //enable pull-down mode
  io_conf.pull_down_en = 0;
  gpio_config(&io_conf);
}

void Gpio_deafult_state_set(void)
{
  /* gpio_set_level(RS485_SELECT,0); // for making the RS484 default to receive */  
  gpio_set_level(LED_RX_PIN, 0); 
  gpio_set_level(LED_TX_PIN, 0); 

  gpio_set_level(LED_RX_PIN, 0);
  gpio_set_level(LED_TX_PIN, 0);
}

void Output_pin_config(void)
{
    gpio_config_t io_conf;
    //disable interrupt
    io_conf.intr_type = GPIO_INTR_DISABLE;
    //set as output mode
    io_conf.mode = GPIO_MODE_OUTPUT;
    //bit mask of the pins that you want to set,e.g.GPIO18/19
    io_conf.pin_bit_mask = GPIO_OUTPUT_PIN_SEL;
    //disable pull-down mode
    io_conf.pull_down_en = 0;
    //disable pull-up mode
    io_conf.pull_up_en = 0;
    //configure GPIO with the given settings
    gpio_config(&io_conf);

    Gpio_deafult_state_set();
}

static void IRAM_ATTR plusBtnTimerHandler(void *args)
{
    static int cnt = 0;

    cnt++;
    if(cnt > 1200 && cnt < 1500 )
    {
    #ifdef BUTTON_STATE_NORMAL_OFF
        if (gpio_get_level(PLUS_BTN_PIN) == 0)  //1 -> 0
    #elif defined(BUTTON_STATE_NORMAL_ON)
        if (gpio_get_level(PLUS_BTN_PIN) == 1)  //0 -> 1
    #endif 
        {
            cnt = 0;
            plus_btn_timer_disable();

            //volume+ 
            gVolume++;
            if(gVolume > 8) gVolume = 8;
            gVolumePlusBtnClicked = true;
        }
    }
    else if(cnt > 2000)
    {
    #ifdef BUTTON_STATE_NORMAL_OFF
        if (gpio_get_level(PLUS_BTN_PIN) == 0)
    #elif defined(BUTTON_STATE_NORMAL_ON)
        if (gpio_get_level(PLUS_BTN_PIN) == 1)
    #endif        
        {
            plus_btn_timer_disable();
            cnt = 0;
            
            //channel+
            gChannelNum++;
            if(gChannelNum > MAX_CHANNEL_NUM) gChannelNum = MAX_CHANNEL_NUM;
            gChannelPlusBtnClicked = true;
        }
    }
}

static void IRAM_ATTR minusBtnTimerHandler(void *args)
{
    static int cnt = 0;

    cnt++;
    if(cnt > 1200 && cnt < 1500 )
    {
    #ifdef BUTTON_STATE_NORMAL_OFF
        if (gpio_get_level(MIN_BTN_PIN) == 0)
    #elif defined(BUTTON_STATE_NORMAL_ON)
        if (gpio_get_level(MIN_BTN_PIN) == 1)
    #endif
        {
            cnt = 0;
            minus_btn_timer_disable();

            //volume- 
            gVolume--;
            if(gVolume > 8) gVolume = 0;
            gVolumeMinusBtnClicked = true;
        }
    }
    else if(cnt > 2000)
    {
    #ifdef BUTTON_STATE_NORMAL_OFF
        if (gpio_get_level(MIN_BTN_PIN) == 0)
    #elif defined(BUTTON_STATE_NORMAL_ON)
        if (gpio_get_level(MIN_BTN_PIN) == 1)
    #endif
        {
            minus_btn_timer_disable();
            cnt = 0;
            
            //channel-
            if(gChannelNum > 0 && gChannelNum < MAX_CHANNEL_NUM)
            {
                gChannelNum--;
                if(gChannelNum > MAX_CHANNEL_NUM) gChannelNum = 0;
                gChannelMinusBtnClicked = true;
            }
        }
    }
}
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

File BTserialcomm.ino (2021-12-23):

// upload this sketch to facilitate AT command communication betweeen phone and device.
///////////////////////////////////////////////////////////////////////////////////////////////////////

 #include "BluetoothSerial.h"

  #if !defined(CONFIG_BT_ENABLED) || !defined(CONFIG_BLUEDROID_ENABLED)
  #error Bluetooth is not enabled! Please run `make menuconfig` to and enable it
  #endif

  BluetoothSerial SerialBT;

 void setup() {
   Serial2.begin(9600, SERIAL_8N1, 16, 17);
    Serial.begin(115200);
    SerialBT.begin("ESP32MORD"); //Bluetooth device name
   Serial.println("The device started, now you can pair it with bluetooth!");
 }

  void loop() {
   if (Serial2.available()) {
   SerialBT.write(Serial2.read());
   }
   if (SerialBT.available()) {
   Serial2.write(SerialBT.read());
  }
  delay(20);
  }


//#include <esp_bt.h>
//
//void setup()
//{
//  btStop();
//  esp_bt_controller_disable();
//
//}
//
//void loop()
//{}

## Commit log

2023-02-20 Add files via upload
    https://www.instructables.com/Arduino-Walkie-Talkie/
2023-03-07 Add files via upload
    Here is the FW. Please note, the firmware is not developed by us, this is the work of the creator, DragonTV. KM6WZM Please find him at https://www.instructables.com/member/dragonbtv/ The FirmWare is 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
    Thanks!
2023-05-26 unzip design file.zip
    [SDR_wt.PrjPcb, SDR_wt_PCBlib.PcbLib, SDR_wt_SchLib.SchLib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]
2023-05-26 unzip SCRD 3D
    [V01 - base-1.STL, button.STL, s1.STL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]
2023-05-26 moved datasheets, components and schematics pdf
    [release BOM.xls]
2023-06-02 Revert "A way better tree for this repository..."
    [SDR_wt.PrjPcb, SDR_wt_PCBlib.PcbLib, SDR_wt_SchLib.SchLib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]
2023-08-25 unzip all archives
    [SDR_wt.PrjPcb, SDR_wt_PCBlib.PcbLib, SDR_wt_SchLib.SchLib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]
2023-08-26 Invert TX LED state
    [gpio.c]
2023-08-26 fix no way to rx without tone squelch
    [uart.c, ui.c]
2023-08-27 Update uart.c fix typo
    [uart.c]
